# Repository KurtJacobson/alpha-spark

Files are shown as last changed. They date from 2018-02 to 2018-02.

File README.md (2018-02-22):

# Alpha Spark

Raspberry Pi code for measuring the interaction rate of alpha particles in a
Chang-Rosenblum type alpha particle detector.

## Schematic

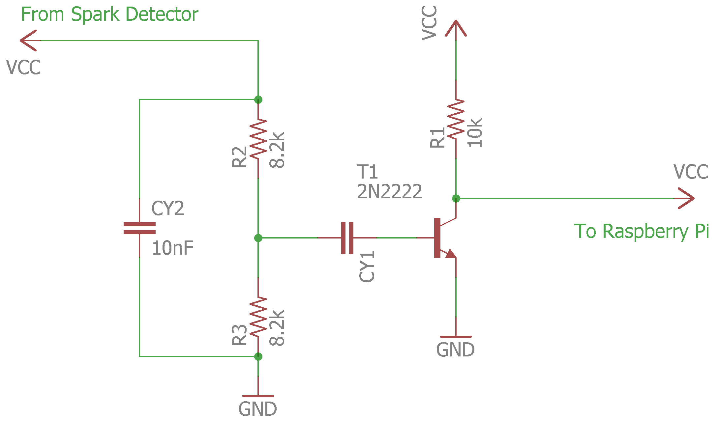
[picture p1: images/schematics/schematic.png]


## Block Diagram

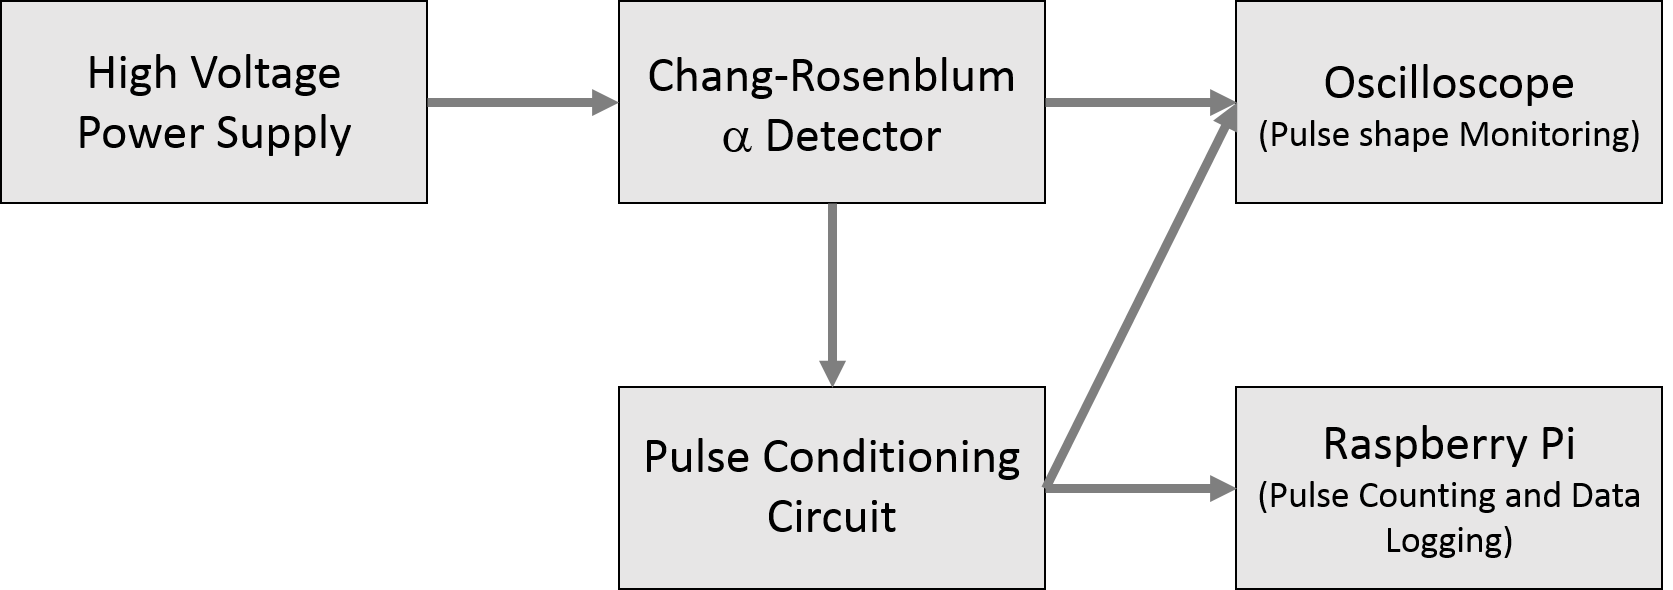
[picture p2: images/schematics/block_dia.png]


## Contributors

  * Shawn Sinclare
  * Andrew Jones
  * Christina Kirby
  * Kurt Jacobson

## Advisors

  * Dr. Eduardo B. Farfan
  * Dr. Sandip Das

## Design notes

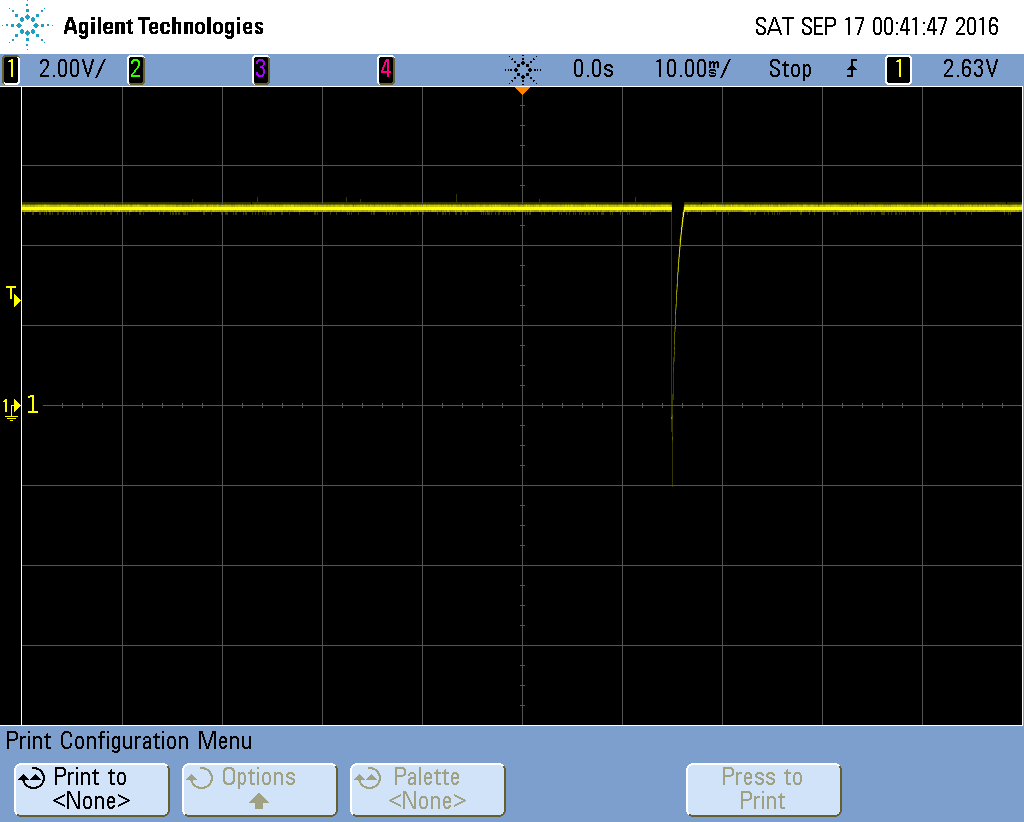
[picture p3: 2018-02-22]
images/pulses/scope_1.bmp

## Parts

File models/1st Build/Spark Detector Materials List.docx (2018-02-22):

Spark Detector Materials List

Anode Wire:

~.003” Tungsten Filament Wire

http://www.ebay.com/itm/Tungsten-wire-0-1-mm-0-0041-10m-33-ft-/261970207722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

Anode Wire tie offs:

.375” X 16ga Brass escutcheon pins

http://www.mcmaster.com/#97936a132/=12xx2ko

Anode Wire Busbars:

.25” X .50” X 12” Copper or Aluminum bar.

http://www.mcmaster.com/#8964k4/=12xx5r5

Drills for making busbars:

2 each of:

#55 – McMaster # 30585A71 (http://www.mcmaster.com/)

#54 – McMaster # 30585A69 (http://www.mcmaster.com/)

#53 - McMaster # 30585A68

Detector Body:

.75” X 3” X 12” Natural Delrin Bar (Black Delrin should be avoided as it contains carbon black and is very slightly conductive.)

http://www.mcmaster.com/#8739k45/=12xwx2e

Cathode Plate:

.125” X 2” X 12” Aluminum Bar

http://www.mcmaster.com/#8975k582/=12xx8ah

Miscellaneous machine screws, taps, mills &c. which I have and we can make use of.

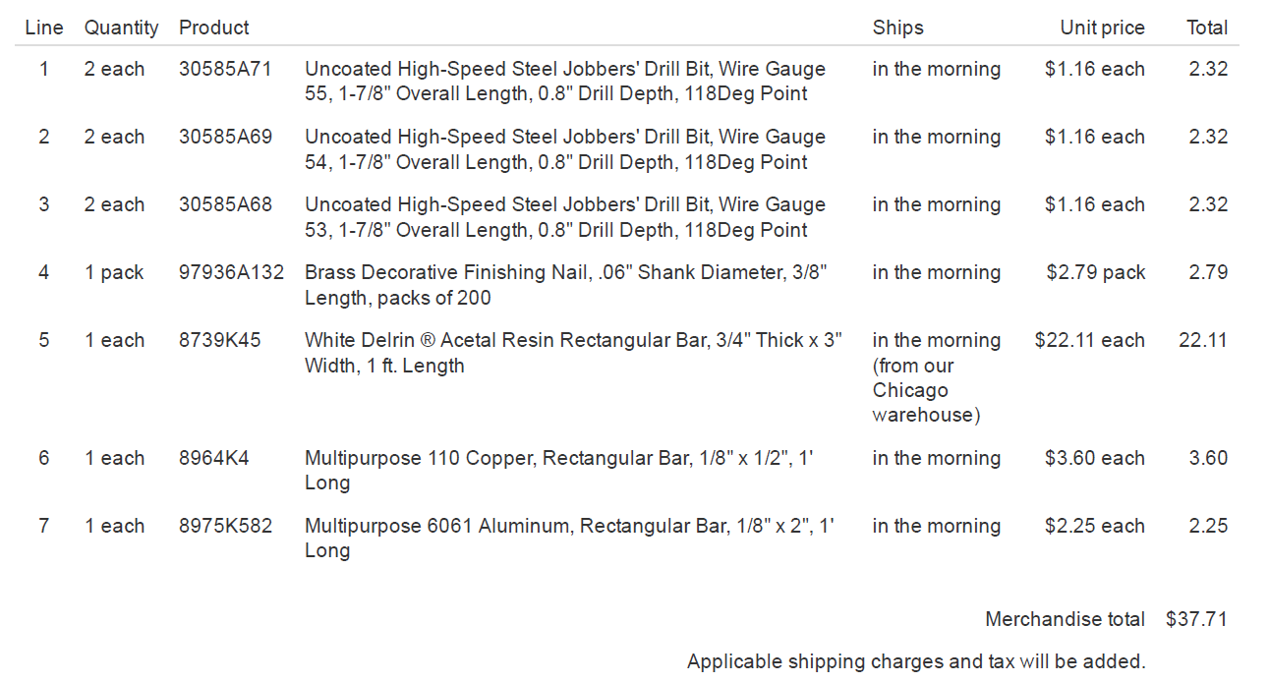
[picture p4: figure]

Below is the complete McMaster order. The only thing missing is the Tungsten wire, which McMaster caries (#3775K37), but for $106 1/16 lbm.

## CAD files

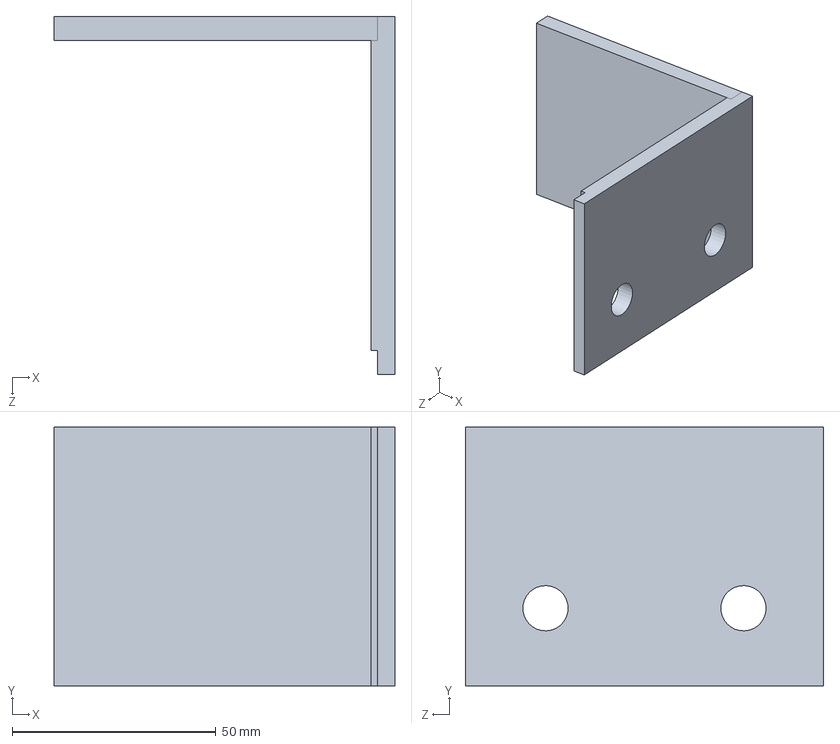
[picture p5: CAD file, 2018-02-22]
models/2nd Build/Side Assy.SLDASM
83.6 x 63.5 x 87.9 mm
Side x 2

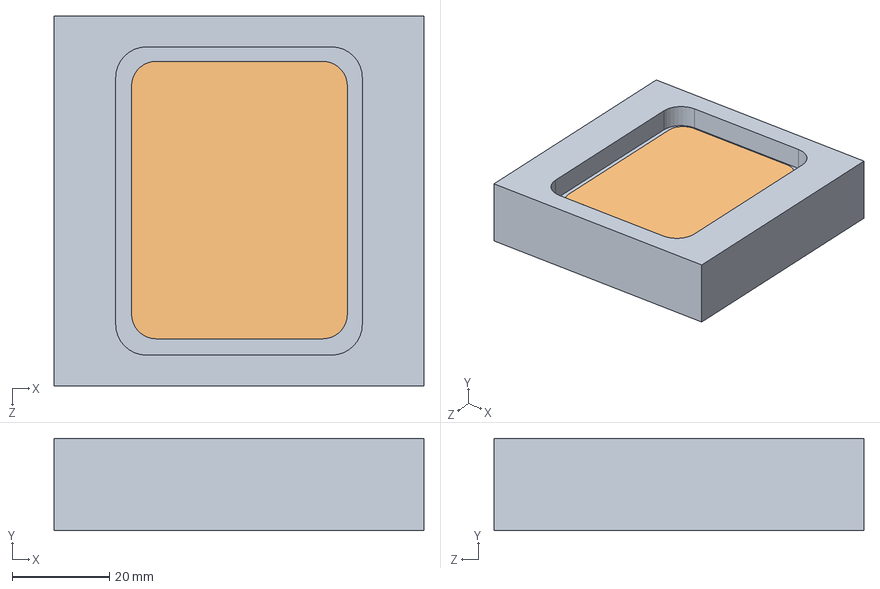
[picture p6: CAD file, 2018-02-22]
models/detector body and plate.SLDPRT.SLDASM
76.2 x 19.1 x 76.2 mm
detector body
plate

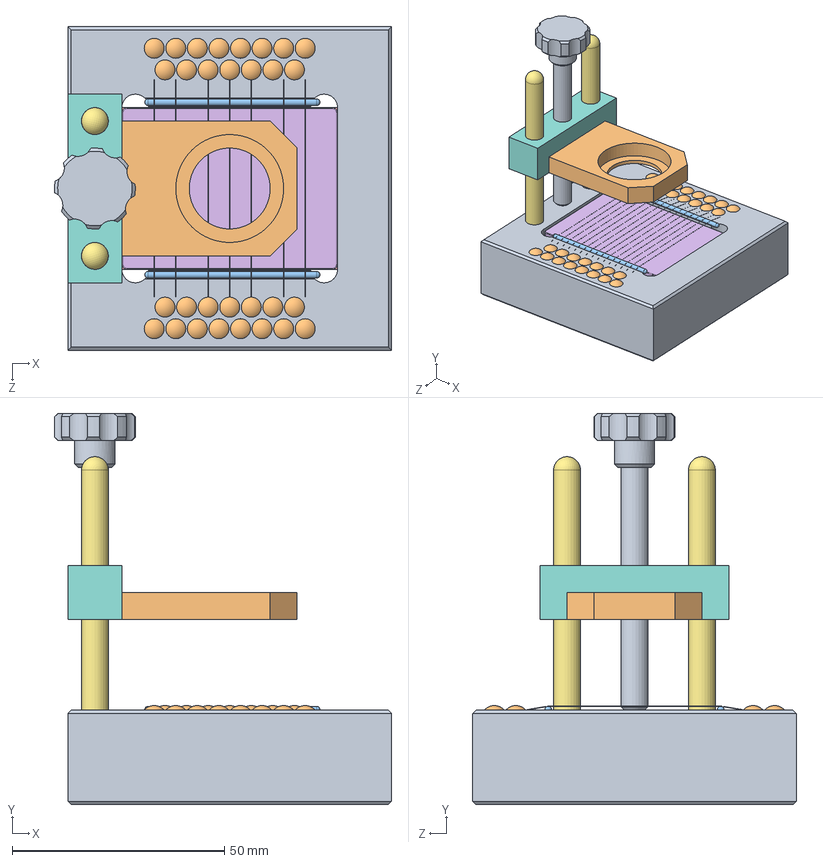
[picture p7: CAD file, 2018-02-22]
models/1st Build/CSC Assy.SLDASM
79.4 x 92.1 x 76.2 mm
CSC Body
3 X 3 Rivet x 30
Nut x 2
Wire x 16
Plate Piston
Plate
Guide Post x 2
Slide
Screw
Source Holder

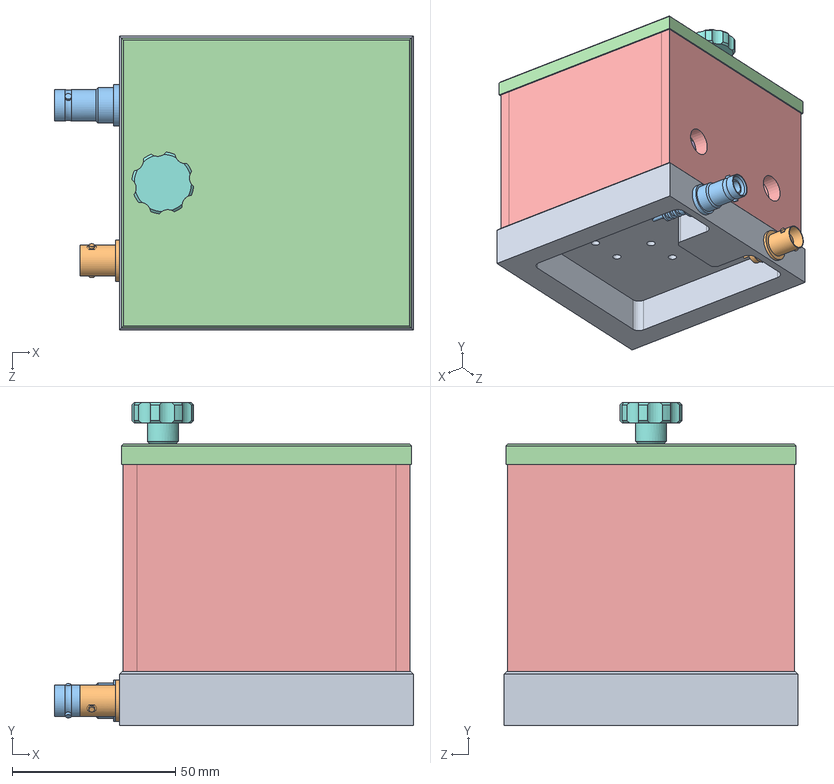
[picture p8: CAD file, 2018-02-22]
models/2nd Build/CSC Assy.SLDASM
110.0 x 99.1 x 90.2 mm
CSC Body
3 X 3 Rivet x 30
Nut x 2
Wire x 16
Plate
Guide Post x 2
Slide
Screw
Source Holder
ACX1046-ND_BNC
SHV Con
Top
Side x 4

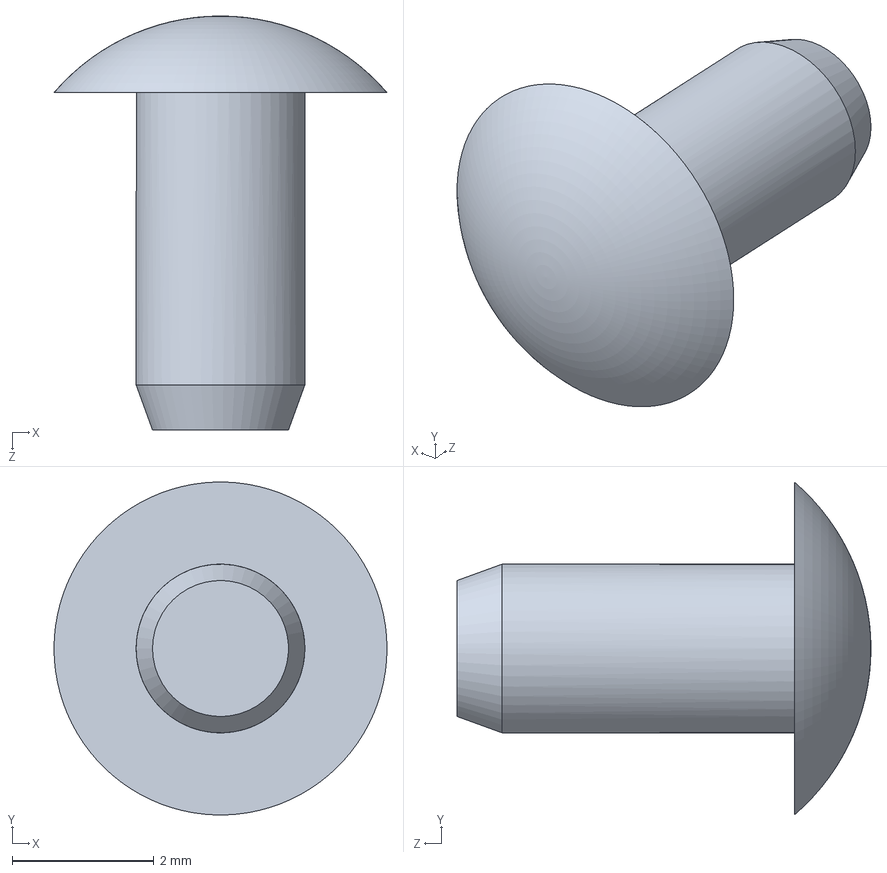
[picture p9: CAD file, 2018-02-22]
models/1st Build/3 X 3 Rivet.SLDPRT
4.70 x 4.70 x 5.84 mm

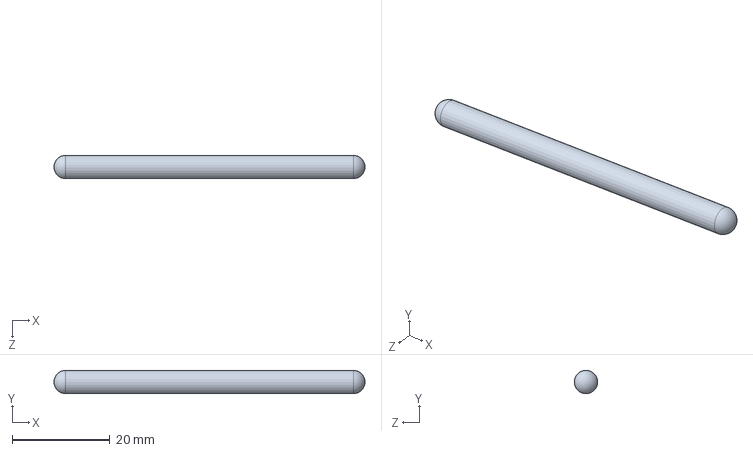
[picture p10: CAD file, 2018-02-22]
models/1st Build/Rod.SLDPRT
63.5 x 4.75 x 4.76 mm

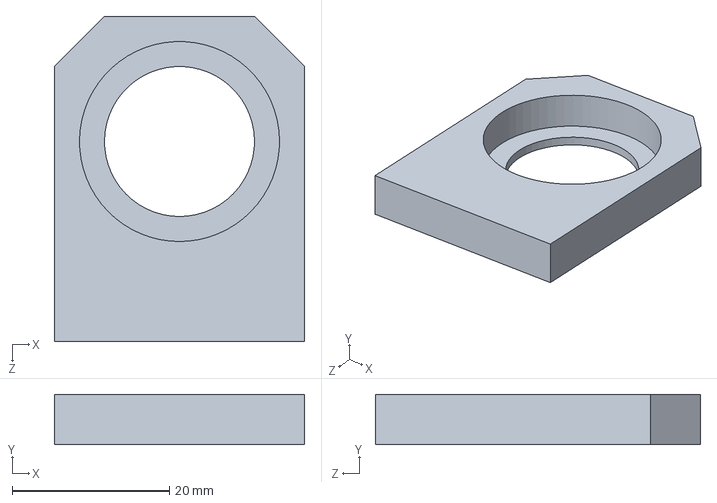
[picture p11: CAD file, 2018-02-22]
models/2nd Build/Source Holder.SLDPRT
31.8 x 6.35 x 41.3 mm

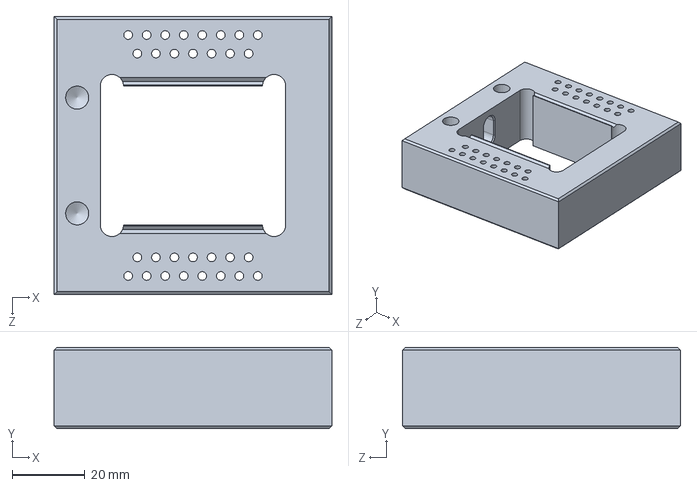
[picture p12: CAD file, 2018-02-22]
models/1st Build/CSC Body.SLDPRT
76.2 x 22.2 x 76.2 mm

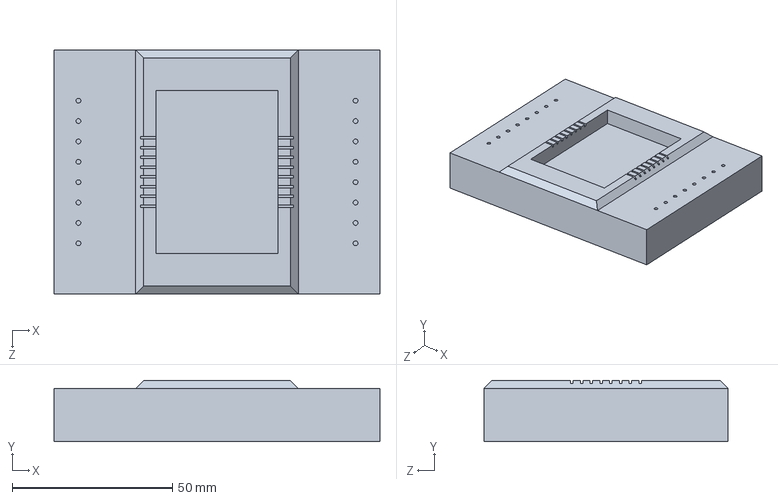
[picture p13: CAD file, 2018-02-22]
models/2nd Build/Spark Counter.SLDPRT
101.6 x 19.1 x 76.2 mm

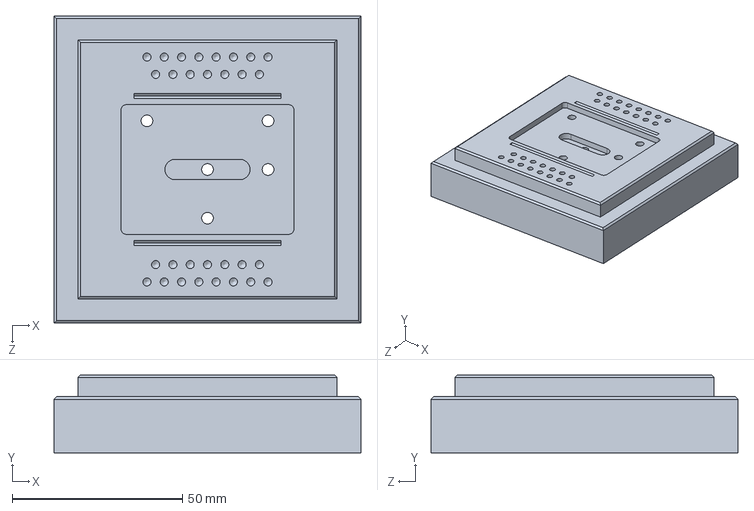
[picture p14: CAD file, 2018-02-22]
models/2nd Build/CSC Body.SLDPRT
90.2 x 22.9 x 90.2 mm

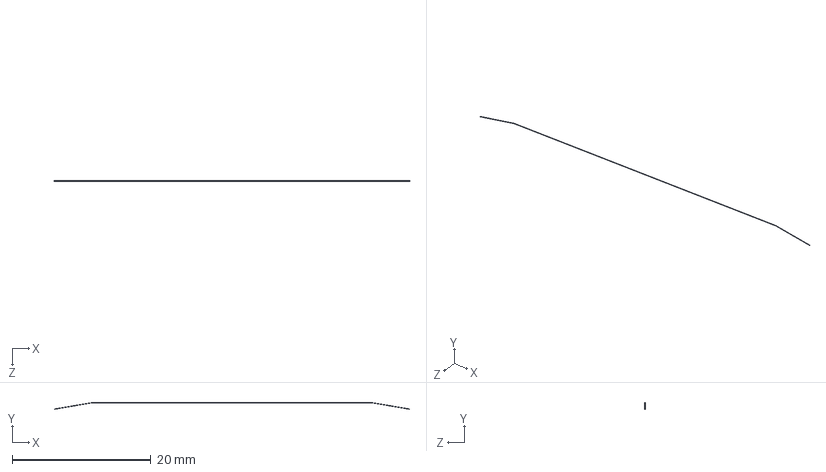
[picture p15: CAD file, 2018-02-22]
models/1st Build/Wire.SLDPRT
51.2 x 0.951 x 0.0508 mm

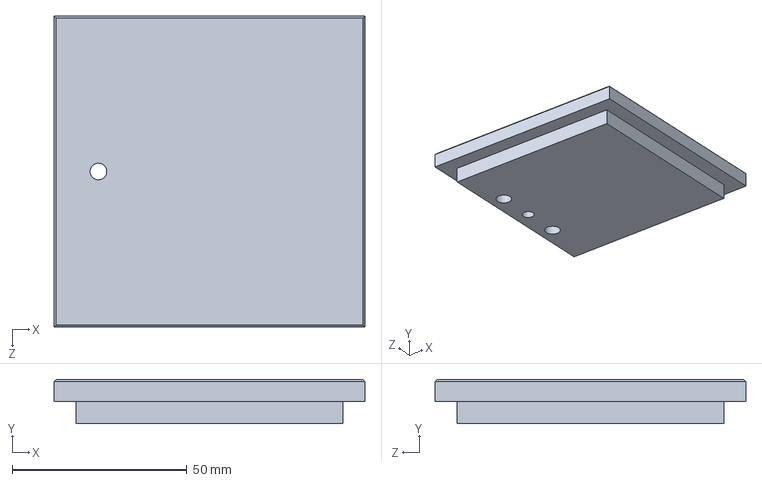
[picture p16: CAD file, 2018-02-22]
models/2nd Build/Top.SLDPRT
88.9 x 12.7 x 88.9 mm

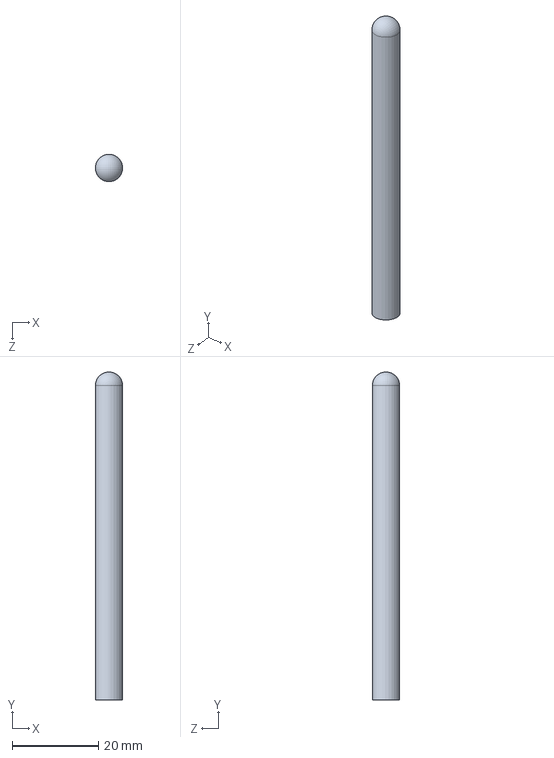
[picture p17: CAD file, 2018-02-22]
models/1st Build/Guide Post.SLDPRT
6.34 x 76.2 x 6.35 mm

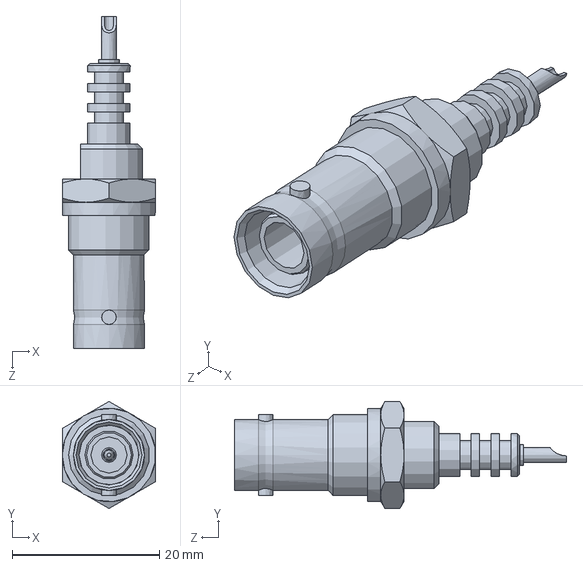
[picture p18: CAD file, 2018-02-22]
models/2nd Build/SHV Con.SLDPRT
12.7 x 14.5 x 45.1 mm

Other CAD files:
models/1st Build/Source.SLDPRT
models/2nd Build/Slide.SLDPRT
models/1st Build/Plate.SLDPRT
models/2nd Build/SHV.SLDPRT
models/1st Build/CSC Body .SLDDRW
models/1st Build/Nut.SLDPRT
models/1st Build/Plate Piston.SLDPRT
models/1st Build/Screw.SLDPRT
models/1st Build/Slide.SLDPRT
models/2nd Build/ACX1046-ND_BNC.SLDPRT
models/2nd Build/CSC Body .SLDDRW
models/2nd Build/Guide Post.SLDPRT
models/2nd Build/Nut.SLDPRT
models/2nd Build/Plate Piston.SLDPRT
models/2nd Build/Plate.SLDPRT
models/2nd Build/Screw.SLDPRT
models/2nd Build/Side.SLDPRT
models/2nd Build/Source.SLDPRT
models/2nd Build/Top Cover.SLDPRT
models/2nd Build/Wire.SLDPRT

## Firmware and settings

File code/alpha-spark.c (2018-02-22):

#include <stdio.h>
#include <wiringPi.h>
#include <stdlib.h>

int main(void)
{
    wiringPiSetupGpio();

    pinMode(27, INPUT);
    digitalWrite(27,HIGH);

    int count = 0;
    int startTime = 0;
    int countPerSec = 0;
    int timePreviousPrint = 0;
    int lastRead = 0;
    float countPerMinute = 0;
    char time[10];
    char fName[15];


    printf("Input save to filename:" );
    fgets(fName,15,stdin);
    FILE *fp;
    fp=fopen(fName,"w");
    fprintf(fp , "TIME\tcpm\n");


    printf("Input Count Time: ");
    fgets(time,10,stdin);
    printf("Counting for %s",time);

    int timeInt = atoi(time);

    int startTime = millis();
    timePreviousPrint= millis();

    while(millis()-startTime <= timeInt*1000)
    {

        if (millis()-timePreviousPrint >= 1000)
        {
            timePreviousPrint = millis();
            printf("%d\t%d\n", (millis()-startTime+1000)/1000 , countPerSec);
            fprintf(fp, "%d\t%d\n", (millis()-startTime+1000)/1000 , countPerSec);
            countPerSec = 0;
        }

        if (digitalRead(27)==LOW && lastRead==1)
        {
            count++;
            countPerSec++;
            lastRead=0;
        }

        else if (digitalRead(27)==HIGH)
        {
            lastRead=1;
        }

    }

    printf("\n count= %d   timeInt= %d" , count, timeInt);
    countPerMinute = count*(60.0F/timeInt);
    printf("\nAvg cpm was: %f \n", countPerMinute);
    fclose(fp);

    return 0;

}

//Notes: compile command: gcc -Wall -lwiringPi kurt2.c -o kurt2
// to run program: sudo ./kurt2
